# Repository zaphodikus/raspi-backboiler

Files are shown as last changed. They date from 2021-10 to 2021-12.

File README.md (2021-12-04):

# raspi-backboiler
Back boiler monitoring app in python.

This is a scratchpad, as with most projects, it will be messy. This repo serves as a way to move code between a Rasberry Pi 4 and my desktop to make editing and so on easier. Sensors include a set of MAX6675's and DS18B20's on SPI and 1WD.

#Dependencies
Dependencies are on the adafruit boards libraries https://pypi.org/project/Adafruit-Blinka/
* todo: add links to hardware diagrams and tutorials i used
* todo: the pinout printable template
* todo: add python modules
* todo: add matplotlib into this
* todo: add flask web server to the app

#H/W&S/W Components
```
All this will run on a Raspbery Pi 4 (4BG):
+--------------+  +--------------+  +--------------+     
|              |  |              |  |              |     
| Temperature  |  |  SQLLITE     |  |  Datalogger  |     
|   Sensors    |  |              |  |   history    |     
|              |  |              |  |              |     
+--------------+  +--------------+  +--------------+     
                                                         
+--------------+  +--------------+  +--------------+                     
|              |  |              |  |              |                     
|  Pollution   |  |  Arduino     |  |  Flask Web   |                     
|  Sensors     |  |   ADC        |  |    Server    |                     
|              |  | conversion   |  |              |                     
+--------------+  +--------------+  +--------------+                     
```
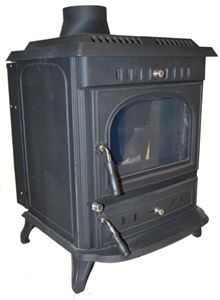
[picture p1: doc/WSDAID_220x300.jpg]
Back Boiler


This will mostly be attached to the back-boiler and plumbing and other parts of a Warrior 13KW 
stove. I have features the stove in a YT channel called `100 logfires` , which currently has 2 
subscribers. That;s how many days of a year this system runs for, the rest of the time, it will 
be pretty boring room-temperature-like stuff going on with the exception of the solar panels in 
the summer.

##Sensors 1WD:
For the range 10-125°C, all sensors are non intrusive.
* 4* DS18B20 sensors (boiler hot side) 
* 1* DS18B20 sensors (pump line)
##Sensors SPI:
For the range 100-600°C (expected max 400°C)
* 1* MAX6675 thermocouple (flue temp)

##Planned sensors:
Will connect to a second raspi in loft space 
* 1* Arduino ADC into SPI port (pollution sensor MX1)
* 1* Arduino ADC into SPI port (pollution sensor MX2)
* Serial data acquisition from solar system : 
  todo link blog post for details
  
# Software
Multiple data acquisition and data logging and rendering apps.
todo: configuration notes

* Acquisition app: Read DS81B20's and the MAX6675's and write into sqllite db, write each to 1 row of database at 5 second intervals for live data values. 
  Data will also get piped via a filter into a rotating data-logger table, and eventually into a cloud. 
* Data-logger routine runs in the acquisition app, will run every 1 minute and filter and deadband the data to save space, into a second table.
  Deadband threshold and timer to ensure a value is written every hour, but no more than every minute. Logger will also use a second filter to write a row into a google docs sheet at least once per 24 hours. Each sensor will have it's own deadband configuration.
* Flask Web server, very basic phase1. Read just the last valid values and display, allow changing of sensor names.
* Flask Web server phase2. Read history sql table and render matplotlib static graphic.
* Acquisition phase2 : Acquisition app to integrate Arduino ADC inputs to read 2 analog values
* Acquisition phase3 : Adds a second raspberry pi. Separate serial data Acquisition app with ethernet TCP "chat socket" conversion and a new "chat protocol". "chat socket acessible from the main acquisition app and added up to 5 new solar panel datas to log with the temperatures. Adapt the logger accordingly with the new datas. 
  Move arduino atmosphere sensors to also use the ethernet "chat socket" protocol instead of directly to host.
* Connect main Raspberry pi to public internet

#Installation steps
(todo : Script these machine setup steps)
 - enable 1WD in sudo raspi-config
 - enable spi driver in sudo raspi-config
 - enable autologon on start 
 - reboot Raspberry pi
```
 sudo apt-get install python3-pip
 sudo pip3 install --upgrade setuptools 
 pip3 install adafruit_blinka
 pip3 install psutil
 pip3 install serial
 sudo pip3 install adafruit-circuitpython-bme280
 ```
Data modules
```
 sudo apt-get install libatlas-base-dev
```
 - Install ^^ first since numpy wants some c library called `libf77blas.so.3`
``` 
 pip3 install pandas
 pip3 install matplotlib
 pip3 install seaborn
 pip3 install flask
```
Flask app setup
```
export FLASK_APP=test.py
```

## Google docs Integration
(todo)
* setup auth token https://developers.google.com/sheets/api/quickstart/python
* pip install --upgrade google-api-python-client google-auth-httplib2 google-auth-oauthlib
* todo: link to solar panel protocol
* todo link to the old 100 logfires YT channel

## System Startup
todo : Ramdisk for sqllite temporary databases

todo : start IO server on startup and use the ramdisc for high speed logs

todo : start the web server on startup

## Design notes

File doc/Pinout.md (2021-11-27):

# Pinout docs

### Art
It's a bit more work than one might like to get any DIY project documented properly. 
At least to the level where the maker could come back 20 years on and reproduce the 
same working artefact from said documentation, but it's also fun to try and do so in a 
more editable fashion, so we will give ascii art a go. The template I use is a modified 
version from https://github.com/tvierb/raspberry-ascii

                             .___.              
                    +3V3-- 1-|O O|- 2--+5V
          (SDA)  GPIO2---- 3-|O O|- 4--+5V
         (SCL1)  GPIO3---- 5-|O O|- 6---GND
    (GPIO_GLCK)  GPIO4---- 7-|O O|- 8-----GPIO14 (TXD0)
                     GND-- 9-|O.O|-10-----GPIO15 (RXD0)
    (GPIO_GEN0) GPIO17----11-|O O|-12-----GPIO18 (GPIO_GEN1)
    (GPIO_GEN2) GPIO27----13-|O O|-14---GND
    (GPIO_GEN3) GPIO22----15-|O O|-16-----GPIO23 (GPIO_GEN4)
                    +3V3--17-|O O|-18-----GPIO24 (GPIO_GEN5)
     (SPI_MOSI) GPIO10----19-|O.O|-20---GND
     (SPI_MISO) GPIO9 ----21-|O O|-22-----GPIO25 (GPIO_GEN6)
     (SPI_SCLK) GPIO11----23-|O O|-24-----GPIO8  (SPI_C0_N)
                     GND--25-|O O|-26-----GPIO7  (SPI_C1_N)
       (EEPROM) ID_SD-----27-|O O|-28-----ID_SC Reserved for ID EEPROM
                GPIO5-----29-|O.O|-30---GND
                GPIO6-----31-|O O|-32-----GPIO12
                GPIO13----33-|O O|-34---GND
                GPIO19----35-|O O|-36-----GPIO16
                GPIO26----37-|O O|-38-----GPIO20
                     GND--39-|O O|-40-----GPIO21
                             '---'

                           .___.
                 GPIO21-40-|O O|-39-GND   
                 GPIO20-38-|O O|-37-GPIO26
                 GPIO16-36-|O O|-35-GPIO19
                    GND-34-|O O|-33-GPIO13
                 GPIO12-32-|O O|-31-GPIO6 
                    GND-30-|O O|-29-GPIO5 
      (Reserved) ID_SC--28-|O O|-27-ID_SD  (EEPROM)
      (SPI_C1_N) GPIO7--26-|O O|-25-GND   
      (SPI_C0_N) GPIO8--24-|O O|-23-GPIO11 (SPI_SCLK)
     (GPIO_GEN6) GPIO25-22-|O O|-21-GPIO9  (SPI_MISO)
                    GND-20-|O O|-19-GPIO10 (SPI_MOSI)
     (GPIO_GEN5) GPIO24-18-|O O|-17-+3V3  
     (GPIO_GEN4) GPIO23-16-|O O|-15-GPIO22 (GPIO_GEN3)
                    GND-14-|O O|-13-GPIO27 (GPIO_GEN2)
     (GPIO_GEN1) GPIO18-12-|O O|-11-GPIO17 (GPIO_GEN0)
          (RXD0) GPIO15-10-|O O|-9--GND   
          (TXD0) GPIO14--8-|O O|-7--GPIO4  (GLCK)
                    GND--6-|O O|-5--GPIO3  (SCL1)
                    +5V--4-|O O|-3--GPIO2  (SDA)
                    +5V--2-|O O|-1--+3V3  
                           '---'

               (   ( (   (                  
               G   G G   G ( ( (            
               P   P P   P S S R            
               I   I I   I P P e            
               O   O O   O I I s            
           ( ( _   _ _   _ _ _ e            
           T R G   G G   G C C r            
           X X E   E E   E 0 1 v            
           D D N   N N   N _ _ e            
           0 0 1   4 5   6 N N d            
           ) ) )   ) )   ) ) ) )            
                                        
           G G G   G G   G G G I   G   G G G
           P P P   P P   P P P D   P   P P P
           I I I   I I   I I I _   I   I I I
     + + G O O O G O O G O O O S G O G O O O
     5 5 N 1 1 1 N 2 2 N 2 8 7 C N 1 N 1 2 2
     V V D 4 5 8 D 3 4 D 5 | | | D 2 D 6 0 1
     | | | | | | | | | | | | | | | | | | | |
     | | | | 1 1 1 1 1 2 2 2 2 2 3 3 3 3 3 4
     2 4 6 8 0 2 4 6 8 0 2 4 6 8 0 2 4 6 8 0
     M M M M M M M M M M M M M M M M M M M M
    +---------------------------------------+
    |O O O O O O O O O O O O O O O O O O O O|
    |                                       |
    |O O O O O O O O O O O O O O O O O O O O|
    +---------------------------------------+
     M M M M M M M M M M M M M M M M M M M M
     1 3 5 7 9 1 1 1 1 1 2 2 2 2 2 3 3 3 3 3
     | | | | | 1 3 5 7 9 1 3 5 7 9 1 3 5 7 9
     | | | | | | | | | | | | | | | | | | | |
     + G G G G G G G + G G G G I G G G G G G
     3 P P P N P P P 3 P P P N D P P P P P N
     V I I I D I I I V I I I D _ I I I I I D
     3 O O O   O O O 3 O O O   S O O O O O  
       2 3 4   1 2 2   1 9 1   D 5 6 1 1 2  
               7 7 2   0   1         3 9 6  
                            
       ( ( (   ( ( (   ( ( (   (
       S S G   G G G   S S S   E
       D C L   P P P   P P P   E
       A L C   I I I   I I I   P
       ) 1 K   O O O   _ _ _   R
         ) )   _ _ _   M M S   O
               G G G   O I C   M
               E E E   S S L   )
               N N N   I O K
               0 2 3   ) ) )
               ) ) )
    
                             ( ( (          
                     ( ( (   G G G          
                     S S S   P P P          
                 (   P P P   I I I          
                 E   I I I   O O O          
                 E   _ _ _   _ _ _   ( (    
                 P   S M M   G G G   G S (  
                 R   C I O   E E E   L C S  
                 O   L S S   N N N   C L D  
                 M   K O I   3 2 0   K 1 A  
                 )   ) ) )   ) ) )   ) ) )  
                                            
       G G G G G I   G G G   G G G   G G G  
       P P P P P D   P P P   P P P   P P P  
       I I I I I _   I I I + I I I   I I I +
     G O O O O O S G O O O 3 O O O G O O O 3
     N 2 1 1 6 5 D N 1 9 1 V 2 2 1 N 4 3 2 V
     D 6 9 3 | | | D 1 | 0 3 2 7 7 D | | | 3
     | | | | | | | | | | | | | | | | | | | |
     3 3 3 3 3 2 2 2 2 2 1 1 1 1 1 | | | | |
     9 7 5 3 1 9 7 5 3 1 9 7 5 3 1 9 7 5 3 1
     M M M M M M M M M M M M M M M M M M M M
    +----------------------------------------+
    |O O O O O O O O O O O O O O O O O O O O |
    |                                        |
    |O O O O O O O O O O O O O O O O O O O O |
    +----------------------------------------+
     M M M M M M M M M M M M M M M M M M M M
     4 3 3 3 3 3 2 2 2 2 2 1 1 1 1 1 8 6 4 2
     0 8 6 4 2 0 8 6 4 2 0 8 6 4 2 0 | | | |
     | | | | | | | | | | | | | | | | | | | |
     G G G G G G I G G G G G G G G G G G + +
     P P P N P N D P P P N P P N P P P N 5 5
     I I I D I D _ I I I D I I D I I I D V V
     O O O   O   S O O O   O O   O O O      
     2 2 1   1   C 7 8 2   2 2   1 1 1      
     1 0 6   2         5   4 3   8 5 4      
                                      
                 ( ( ( (   ( (   ( ( (
                 R S S G   G G   G R T
                 e P P P   P P   P X X
                 s I I I   I I   I D D
                 e _ _ O   O O   O 0 0
                 r C C _   _ _   _ ) )
                 v 1 0 G   G G   G
                 e _ _ E   E E   E
                 d N N N   N N   N
                 ) ) ) 6   5 4   1
                       )   ) )   )

## Sensors
**DS81B20 (1WD) Temp sensors** 

                      .___.              
                 -- 1-|O O|- 2--                Terminal block
                 -- 3-|O O|- 4--                  +------+
                 -- 5-|O O|- 6--        (black) - |Gnd   |
             1WD -- 7-|O O|- 8--        (yellow)- |sense |
             Gnd -- 9-|O.O|-10--        (red)   - |3V3   |
                 --11-|O O|-12--                  +------+
                 --13-|O O|-14--
                 --15-|O O|-16--
             3v3 --17-|O O|-18--
                 --19-|O.O|-20--
                 --21-|O O|-22--
                 --23-|O O|-24--
                 --25-|O O|-26--
                 --27-|O O|-28--
                 --29-|O.O|-30--
                 --31-|O O|-32--
                 --33-|O O|-34--
                 --35-|O O|-36--
                 --37-|O O|-38--
                 --39-|O O|-40--
                      '---'

 - 1WD need 4K7 Ohm pull-up - connect to the DS81B20 one-wire pin on the sensor.

**MAX6675(SPI) Thermocouple**   

                      .___.              
                 -- 1-|O O|- 2--                   Header
                 -- 3-|O O|- 4--                  +------+
                 -- 5-|O O|- 6--        (black) - |Gnd O |
                 -- 7-|O O|- 8--        (red)   - |3v3 O |
             Gnd -- 9-|O.O|-10--        (   )   - |SCK O |
                 --11-|O O|-12--        (   )   - | CS O |
                 --13-|O O|-14--        (   )   - | DO O |
                 --15-|O O|-16--                  +------+
             3v3 --17-|O O|-18--
                 --19-|O.O|-20--
            MISO --21-|O O|-22--
             SCK --23-|O O|-24--
                 --25-|O O|-26--
                 --27-|O O|-28--
    (GPIO5)  _CS --29-|O.O|-30--
                 --31-|O O|-32--
                 --33-|O O|-34--
                 --35-|O O|-36--
                 --37-|O O|-38--
                 --39-|O O|-40--
                      '---'

 - MISO,SCK are the SPI channel and use GPIO5 as _CHIP-SELECT line.

**BME280(SPI) Pressure sensor BMP280**   

                      .___.              
                 -- 1-|O O|- 2--                   Header
                 -- 3-|O O|- 4--                  +-------+
                 -- 5-|O O|- 6--        (blk  ) - |3v3  O |
                 -- 7-|O O|- 8--        (wht)   - |Gnd  O |
             Gnd -- 9-|O.O|-10--        (gry)   - |SCK  O |
                 --11-|O O|-12--        (bio)   - |MOSI O |
                 --13-|O O|-14--        (blu)   - |_CS  O |
                 --15-|O O|-16--        (grn)   - |MISO O |                  
             3v3 --17-|O O|-18--                  +-------+
            MOSI --19-|O.O|-20--
            MISO --21-|O O|-22--
             SCK --23-|O O|-24--
                 --25-|O O|-26--
                 --27-|O O|-28--
                 --29-|O.O|-30--
     (GPIO6) _CS --31-|O O|-32--
                 --33-|O O|-34--
                 --35-|O O|-36--
                 --37-|O O|-38--
                 --39-|O O|-40--
                      '---'

 - MOSI, MISO, SCK are the SPI channel and use GPIO6 as _CHIP-SELECT line.

**ASD1115 (I2c)**

                             .___.              
                    +3V3-- 1-|O O|- 2--+5V                 + Header+
          (SDA)  GPIO2---- 3-|O O|- 4--+5V            3V3  |   ( ) |
         (SCL1)  GPIO3---- 5-|O O|- 6---GND           Gnd  |   ( ) |
                      ---- 7-|O O|- 8-----            SCL  |   ( ) |
                     GND-- 9-|O.O|-10-----            SDA  |   ( ) |
                      ----11-|O O|-12-----            ADDR | (Gnd) |
                      ----13-|O O|-14---GND           ALRT | (N/C) | 
                      ----15-|O O|-16-----            A0   |   ( ) | MQ-5
                    +3V3--17-|O O|-18-----            A1   |   ( ) | 
                      ----19-|O.O|-20---GND           A2   |   ( ) |
                      ----21-|O O|-22-----            A3   |   ( ) |
                      ----23-|O O|-24-----                 +-------+
                     GND--25-|O O|-26-----       
                      ----27-|O O|-28-----       
                      ----29-|O.O|-30---GND
                      ----31-|O O|-32----- 
                      ----33-|O O|-34---GND
                      ----35-|O O|-36----- 
                      ----37-|O O|-38----- 
                     GND--39-|O O|-40----- 
                             '---'

A few issues for now are that I'm running the May2021 32-bit Rasp OS and really want to update to the 
64bit, so that's a rebuild. Also I intend to rebuild into a SSD, so will have some notes on the 
SSD booting setup work, (when I do that bit) which involves some extra steps you would not have 
suspected.

# References 
(todo: move these to a new doc later)
 - https://github.com/tvierb/raspberry-ascii
 - https://www.raspberrypi-spy.co.uk/2018/02/enable-1-wire-interface-raspberry-pi/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,as%20the%20DS18B20%20temperature%20sensor.
 - https://developers.google.com/sheets/api/quickstart/python

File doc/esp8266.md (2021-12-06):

# Arduino ESP8266 sketch
This is a simple SPI => Serial distance extender. I needed the thermocouple to be on a 5 meter cable, 
which stops working over SPI as a solution.
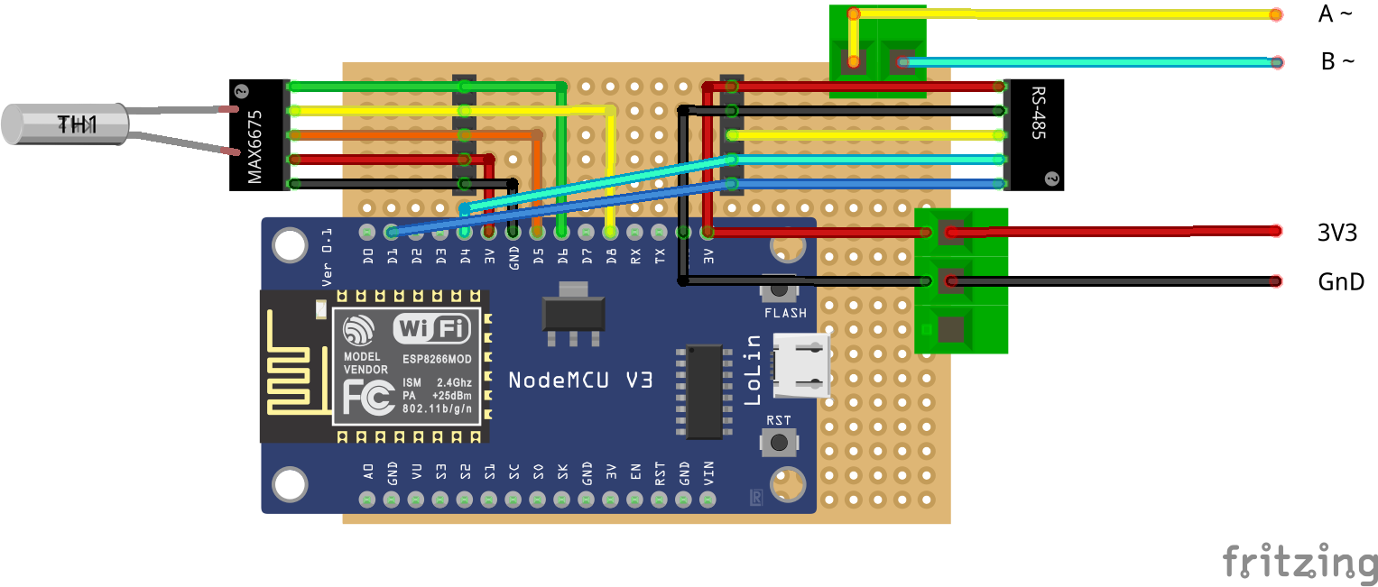
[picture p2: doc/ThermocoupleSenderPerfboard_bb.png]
SPE Extender using ESP8266

The ESP Linoi board is a bit smaller than the regular Arduinos that I have and since it's on hand, 
I'll use whatever I can find that is compact enough to go into a small heatproofed box that will go 
behind the woodstove.

                 +-ANT--+
          ADC0   +      + GPIO16 WAKE
          RES    +      + GPIO5  SCL
          RES    +      + GPIO4  SDA
    SDD3  GPIO10 +      + GPIO0  FLASH
    SDD2  GPIO9  +      + GPIO5  TXD1
    SDD1  MOSI   +      + 3V3
    SDCMD CS     +      + GND
    SDD0  MISO   +      + GPIO14 SCLK
    SDCLK SCLK   +      + GPIO12 MISO
          GND    +      + GPIO13 MOSI  RXD2
          3V3    +    H + GPIO15 CS    TXD2
          EN     +    S + GPIO3  RXD0
          RST    + T  A + GPIO1  TXD0
          GND    + S  L + GND
          VIN    + R  F + 3V3
                 +-USB--+

The ESP carrier boards rather confusingly also have a pinout designation printed on the board that uses a short form.
# MAX6675
              +-ANT--+
              +      +  
              +      +  
              +      +  
              +      +  
              +      +  
              +      + 3v3   MAX6675 VCC 
              +      + GND   MAX6675 Gnd
              +      + SCLK  MAX6675 SCK
              +      + MISO  MAX6675 SO
              +      + 
              +    H + CS    MAX6675 CS 
              +    S +  
              + T  A +  
              + S  L +  
              + R  F +  
              +-USB--+

This is the wiring for the MAX6675 SPI port and the RS485 converter
# RS485

              +-ANT--+             RS485 board
              +      +  
              +      + (GPIO5) D1  -> Enable 
              +      +             NC TX  
              +      + 
              +      + (GPIO2) TX1 -> RX
              +      + 3v3         -- VCC
              +      + GND         -- Gnd
              +      + 
              +      + 
              +      + 
              +    H + 
              +    S +  
              + T  A +  
              + S  L +  
              + R  F +  
              +-USB--+

The transmitter enable is active high on this converter, and tied to transmitter enable which is active HIGH, a bit confusing, because I wnated the reciever to listen all the time and see reflections of every character sent out.
The PI end of the converter was tested using a 3V3 FTDI, and i just tied the enable line LOW so it's permanently listening. THat saves us a GPIO pin on the pi since we never send anything out.

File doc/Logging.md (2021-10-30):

# Datalogging
A quick thing to put up front here, is that I'm going to be using deadbanding to 
save logging space. I'll also use circular buffers on the Edge device for the same 
reason. But I need to expand on this simplistic log compression tactic.

So it's possible to compress timestamps in situ, in my case I'm not doing that at present, 
but presenting timestamps in as integers not string, and lower resolution can cause problems
when you want to log multiple samples at lower resolution in a pinch or even by accident.
 - Compression by resolution: For slow moving data, you don't need milliseconds...unless!
 - Compression by offset: Log one timestamp, and then log just the relative offset as an int (beware wrapping.)
 - Compression by deadband: If the value does not change, don't log it.

## Deadbanding
Always log a sample at startup, regardless, save the time and value in a temporary. For each successive sample, 
that does not differ by value more than the deadband (for example 1 degree celcius), ignore it. After a set interval, 
always log a value anyway. this last bit is important, it covers you for the case where the system shuts down, and you 
don't have a sample to interpolate up to nearby. Typically, deadbands take a lot of tweaking, you want to set them 
so that they give a 10x compression factor. 100x compression is taking it perhaps too far, perhaps reducing the time 
deadband in more.
```
Example: value > 0.5 °C
         time  > 600 seconds
```
Now I want to experiment here and create a "sliding" deadband or logarithmic value sensitive deadband that does not 
fit into the `if abs(value-lastvalue) > deadband:` constraint, because that obviously would not work for something 
like a background radiation sensor reading. So at some point, I'm going to plot some graphs and find a good log base 
and index to use for the value deadbanding at high temperatures, because, for some of the sensors I'm using, accuracy 
is less important than "generally" where it is in relation to where it was a few minutes ago. And that gets hard if we 
want to show cold thermocouples at room temperature, but don't really care about them at all until they get to 
interesting levels like 200 to 300 degrees.

## Circular Buffers
I'm going to not only be creating long term history buffers that span a month at a time, and perhaps some way to 
aggregate those to cover entire lifespan, but I built a circular buffer that works OK-ish in sqlite. It needs 
some optimization, but it's use-able for now. Also going to be pushing those longer term logs into a cloud using 
google spreadsheets. Which should make date mining possible.

## Cloud
Since I'm not confident of getting all things working and not breaking often, and the Raspberry pi Sd card not 
breaking on me. and besides that my programmign skills will corrupt the DB many-many times I'm sure. I'll thus be 
pumping data into a google spreadsheet from early on in the project.

## Matplotlib
And of course using matplotlib. I'm new to the entire topic, so expect some weird stuff to go on in this department 
with bad graphs and bad math.

## Process boundaries
To make some things simpler, the system will use separate processes. Sqllite has some atomicity of some clever SQL 
kind so having one app do data acquisition and pretty much only ever write to the DB, and another app read that data, 
should simplify debugging and force some reduction of complexity. I'm expecting remote sensor data to also come in, 
probably over ethernet, so that will be polled and written to the database, possibly all on the one big sensors app 
initially.
The other app will be the web service, how I do graph "bitmaps" in there with matplotlib in a way that does not overwhelm 
the cpu will be interesting.

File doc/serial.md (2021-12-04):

# Serial
Ran into distance issue and so have to now add serial comms to hook a thermoucouple MAX6675 in to the Raspberry pi over serial

The thermocouple will connect to a ESP8266, and send the readings over RS485 to the pi

Windows tools that are handy for some debugging are:
https://sourceforge.net/projects/com0com/

Loads of notes will be missing here, mainly because this is an area I know pretty well, so anything i omit, just shout and i can fill in all the implcit bits.

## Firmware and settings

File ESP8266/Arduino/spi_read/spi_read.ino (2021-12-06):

/* 
 ESP 8266 (NodeMCU ESP12E)

A simple SPI to RS284 converter that provides us with some distance capability.

Sketch reads the thermocouple, and sends the following string out on TTL port which goes onto RS485.
|value   |meaning                |
|----    |-----                  |
|0x02    |START-OF-TELEGRAM      |
|'5'     |sensor number (ASCII)  |
|0x09    |END-OF-FIELD           |
|'25.0'  |temperature (ASCII)    |
|0x03    |END-OF-TELEGRAM        |

Notes:
Label GPIO  Input Output  Notes
D0  GPIO16  no interrupt  no PWM or I2C support HIGH at boot
used to wake up from deep sleep
D1  GPIO5 OK  OK  often used as SCL (I2C)
D2  GPIO4 OK  OK  often used as SDA (I2C)
D3  GPIO0 pulled up OK  connected to FLASH button, boot fails if pulled LOW
D4  GPIO2 pulled up OK  HIGH at boot
connected to on-board LED, boot fails if pulled LOW
D5  GPIO14  OK  OK  SPI (SCLK)
D6  GPIO12  OK  OK  SPI (MISO)
D7  GPIO13  OK  OK  SPI (MOSI)
D8  GPIO15  pulled to GND OK  SPI (CS)
Boot fails if pulled HIGH
RX  GPIO3 OK  RX pin  HIGH at boot
TX  GPIO1 TX pin  OK  HIGH at boot
debug output at boot, boot fails if pulled LOW
A0  ADC0  Analog Input  X 

Pins:
             +-ANT--+
      ADC0   +      + GPIO16 WAKE
      RES    +      + GPIO5  SCL
      RES    +      + GPIO4  SDA
SDD3  GPIO10 +      + GPIO0  FLASH
SDD2  GPIO9  +      + GPIO5  TXD1
SDD1  MOSI   +      + 3V3
SDCMD CS     +      + GND
SDD0  MISO   +      + GPIO14 SCLK
SDCLK SCLK   +      + GPIO12 MISO
      GND    +      + GPIO13 MOSI  RXD2
      3V3    +    H + GPIO15 CS    TXD2
      EN     +    S + GPIO3  RXD0
      RST    + T  A + GPIO1  TXD0
      GND    + S  L + GND
      VIN    + R  F + 3V3
             +-USB--+

Next step is to use the loop function in a Modbus RTU slave implementation
https://www.arduino.cc/en/ArduinoModbus/ArduinoModbus
and on the pi
https://minimalmodbus.readthedocs.io/en/master/usage.html
which requires https://minimalmodbus.readthedocs.io/en/master/installation.html

FTDI-RS232 3V3
GND   BLACK
CTS#  BROWN
VCC   RED
TXD   ORANGE
RXD   YELLOW
RTS#  GREEN

RS485 board:

------+
      + ENABLE
      + DI
      + DO
      + GnD
      + 3v3
------+

*/

#include<SPI.h>
#include <ESP8266WiFi.h>

const int slaveAPin = D8;  // chip select
const int rsEnPin = D1;    // RS422 enable
// serial message simple farming
const unsigned char START_TEXT = 0x02;
const unsigned char END_FIELD = 0x09;
const unsigned char END_TEXT = 0x03;
int BAUD_RATE = 9600;

void setup() {
  // put your setup code here, to run once:
  WiFi.mode(WIFI_OFF);
  pinMode (slaveAPin, OUTPUT);
  digitalWrite (slaveAPin, LOW);
  pinMode (rsEnPin, OUTPUT);
  digitalWrite (rsEnPin, LOW);
  SPI.beginTransaction(SPISettings(4000000, MSBFIRST, SPI_MODE0));
  SPI.begin();  /* begin SPI */

  Serial.begin(115200);
  Serial1.begin(BAUD_RATE, SERIAL_8N1);
}

uint16_t rawValue;
float celcius;

// --------------------- ReadMax6675 -----------------------------------------------
float ReadMax6675() {
  // https://www.arduino.cc/en/Reference/SPI
  // MAX6675
  digitalWrite (slaveAPin, LOW);
  delay(1);
  rawValue = SPI.transfer(0);
  rawValue<<=8;
  rawValue |= SPI.transfer(0);
  digitalWrite (slaveAPin, HIGH);
  delay(1);
  Serial.print("SPI DATA[");
  Serial.print(rawValue, HEX);
  Serial.println("]");
  //
  if ((rawValue& 0x04) || (0 == rawValue))
  { 
    Serial.println("NAN/invalid");
    rawValue = SPI.transfer(0);
    Serial.print("EAT DATA[");
    Serial.print(rawValue, HEX);
    Serial.println("]");
    return(-1.0);
  }else {
    rawValue >>=3;  // discard lowest 3 bits (status)
    celcius = rawValue*0.25;
    Serial.print(celcius, 3);
    Serial.println(" celcius");
  
    return(celcius);
  }
}

// -------------------- calc_interval ------------------------------------------------
int calc_interval(int count) {
  return((11* 1000 * count / BAUD_RATE) +1);
}

// -------------------- WriteTelegram ------------------------------------------------
void WriteTelegram(int sensor, float value) {
  char telegram[80];
  int offset=0;
  char buff[20];

  digitalWrite (rsEnPin, HIGH);
  telegram[0] = START_TEXT;
  offset+=1;
  sprintf(buff, "%d", sensor);
  strcpy(&telegram[offset], buff);
  offset+=strlen(buff);
  telegram[offset] = END_FIELD;
  offset+=1;
  sprintf(buff, "%4.3f", value);
  strcpy(&telegram[offset], buff);
  offset+=strlen(buff);
  telegram[offset] = END_TEXT;
  Serial1.write(telegram, offset);
  delay(calc_interval(offset));
  digitalWrite (rsEnPin, LOW);

  offset+=1;
  telegram[offset] = 0;
  Serial.println(telegram);
}

void loop() {
  // put your main code here, to run repeatedly:
  float value = ReadMax6675();

  WriteTelegram(5, value);
  delay(200);
}

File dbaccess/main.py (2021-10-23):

import sqlite3 as sql
from platform import python_version
import datetime, time

#import re
#import traceback

# def func(var):
#     stack = traceback.extract_stack()
#     filename, lineno, function_name, code = stack[-2]
#     vars_name = re.compile(r'\((.*?)\).*$').search(code).groups()[0]
#     print (vars_name)
#     return


db_timeformat = "%Y-%m-%d %H:%M:%S"  # hard coded system time formatter

conn = sql.connect('../db/dbaccess')
print(f'This is python version {python_version()}')
print(f"SQLite version {sql.sqlite_version}")

cursorObj = conn.cursor()

cursorObj.execute('drop table if exists sensors')
#cursorObj.execute('SELECT name from sqlite_master where type= "table"')
#print(cursorObj.fetchall())

cursorObj.execute('create table if not exists sensors(address text PRIMARY KEY, display_name text, last_value real, last_live text)')
conn.commit()
cursorObj.execute(f"insert into sensors (address, display_name, last_value, last_live ) values ('aabaaaa1', 'sensor1', 1.1, 'Y')")
conn.commit()

cursorObj.execute("SELECT * FROM sensors")
for row in cursorObj:
    print(row)

cursorObj.execute(f"update sensors set last_value = 42.1 where address = 'aabaaaa1'")
conn.commit()
cursorObj.execute("SELECT * FROM sensors")
for row in cursorObj:
    print(row)


class DbBaseObject(object):
    def __init__(self, connection, tablename, fields):
        self.con = connection
        cursorObj = connection.cursor()
        self.tablename = tablename
        self.fields = fields
        _create_qry = f"create table if not exists {self.tablename}({', '.join(self.fields)})"
        cursorObj.execute(_create_qry)
        connection.commit()

    def _field_names(self):
        return [f.split(' ')[0] for f in self.fields]

    def _create_row(self, values: []):
        assert len(self.fields) == len(values)
        cursorObj = self.con.cursor()
        insert_qry = f"insert into {self.tablename} ({', '.join(self._field_names())} ) " \
                     f"values ({','.join('?'*len(self.fields))})"
        cursorObj.execute(insert_qry, values)
        self.con.commit()

    def _read_row_where(self, key, value):
        cursorObj = self.con.cursor()
        read_qry = f"select * from {self.tablename} where {key} = ?"
        #print(f"exec: {read_qry} \n value={(value)}")
        cursorObj.execute(read_qry, [value])
        return cursorObj.fetchone()

    def _write_row_where(self, key, value, values):
        """
        update a row
        :param key: table KEY
        :param value: value of the table KEY
        :param values: may be a ordered list of all the columns data or a dict with only changed columns
        :return:
        """
        cursorObj = self.con.cursor()
        if isinstance(values, dict):
            fields = values.keys()
            values = values.values()
        else:
            fields = self._field_names()
        write_qry = f"UPDATE {self.tablename} SET {', '.join([( n + ' = ?') for n in fields])} " \
                    f"WHERE {key} = ?"
        #print(f"exec: {write_qry} \n values={[*values,value]}")
        cursorObj.execute(write_qry, [*values, value])
        self.con.commit()


class DbSensor(DbBaseObject):
    def __init__(self, connection, address: str):
        fields = [
            "address text PRIMARY KEY",
            "display_name text",
            "last_value real",
            "last_live text"
        ]
        super().__init__(connection, 'sensors', fields)
        self.address = address
        try:
            self.get()
        except Exception as e:
            self._create_row([f"{address}", f"unknown-{address}", 0.0, datetime.datetime.now().strftime(db_timeformat)])

    def get(self):
        row = self._read_row_where(key='address', value=self.address)
        if row is None:
            raise Exception(f"No matching address '{self.address}'!")
        return row

    def set(self, value=None, name=None):
        values = {}
        if value is not None:
            values['last_value'] = value
            # write a current timestamp
            values['last_live'] = datetime.datetime.now().strftime(db_timeformat)
        if name is not None:
            values['display_name'] = name
        self._write_row_where(key='address', value=self.address, values=values)

    def stale(self):
        row = self.get()
        age = datetime.datetime.now() - datetime.datetime.strptime(row[3], db_timeformat)
        return age.total_seconds()>2


cursorObj.execute('drop table if exists sensors')
sensor = DbSensor(conn, 'ababababab')
sensor.set(name="joes")
stale = False
while not stale:
    stale = sensor.stale()
    print(sensor.get())
    time.sleep(0.1)
print("stale!")

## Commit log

2021-10-23 fixed temp test, but class is now badly interfaced
    [test.py]
2021-10-24 added matplotlib demo and updated redme, added test app for all temp sensors in one
2021-10-29 Added sql circular buffer stage1
2021-11-02 Added webpage, fixed diagram error
    [display.py, sensors.py, test.py]
2021-11-04 change MAC5575 to take a spi, add BMP280
2021-11-04 changed SPI to 5Mhz
2021-11-04 split sensor up
2021-11-04 subclass sensor units and types
2021-11-04 sensors have units, minor subclassing snafus fixed
    [MAX6675.py, test.py]
2021-11-06 Google sheets example and Sensor value loss helper
2021-11-27 fixing object get_sensor_value read failure code
    [MAX6675.py, test.py]
2021-11-27 Fixed class init errors
    [test.py]
2021-11-27 spi tester
2021-12-04 added arduino code only
2021-12-06 humidity rounded to 3 places, added arduino sketch
    [ThermocoupleSenderPerfboard.fzz]
2021-12-11 1 sensor
2021-12-11 max6675 board swapped not sure wht caused the terrible comms tho
    [MAX6675.py, test_spi.py]
